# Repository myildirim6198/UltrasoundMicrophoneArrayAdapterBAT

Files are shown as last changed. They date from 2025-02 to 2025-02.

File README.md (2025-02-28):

# Ultrasound Microphone Array Adapter for recording and locating microbats

This project was developed as a final thesis project. This device records real-time Ultrasound of microbats that is inaudible to the human ears and makes those audible through usage of signal processing algorithms. Additionaly through using digital signal processing algorithms the device is capable of estimating the direction of arrival of the recorded microbat calls based on a microphone array with two MEMS-Microphones. This device is intended to be connected to end devices such as PCs, laptops and smartphones over USB-C. The signal processing is done on the end device.

# Hardware features

- MCU: STM32F730R8T6 with an ARM cortex M7 up to 216 MHz core clock
- Digital Connections: 1x USB-C Fullspeed up to 12 MBit/s, 1x USB-C up to 480 MBit/s (not tested) (connect one port at a time only!)
- Debug: Serial-Wire-Debug
- ADC: PCM1820 2 Channel Audio-ADC up to 192 kHz sampling Frequency
- Pre-amplifier stage: 21 dB
- Adjustable second amplifier stage: up to 40 dB
- Microphones: 2x KNOWLES SPU0410LR5H-QB MEMS-Microphones 3.4 mm gap to each other

# Applications:

- Microphone Arrays
- Ultrasound
- Bat detection and localisation

# Absolute Maximum Ratings

- Supply Voltage: +5V0 to +5V5 (recommended: +5V0) USB feeded

# Manufacturing Information

- Length = 50mm, Width = 50mm, Thickness = 1.6 mm
- Layers = 8
- Min. Via Hole diameter = 0.3 mm
- Via-Type: Epoxy Filled and Capped
- Impedance Control: JLC08161H-2116
- Surface Finish: ENIG
- Material Type: FR-4 TG155

# Progress

- Schematic design: complete
- Layouting: complete
- Manufacturing & assembly: complete
- Bring-Up: complete, all components tested except for USB-HS interface
- Firmware: complete, DMA-Based recording of ultrasound audio
- Software: complete, end-devices can process the recorded ultrasound audio samples frame based

# Examples

3D-representation of the Adapter

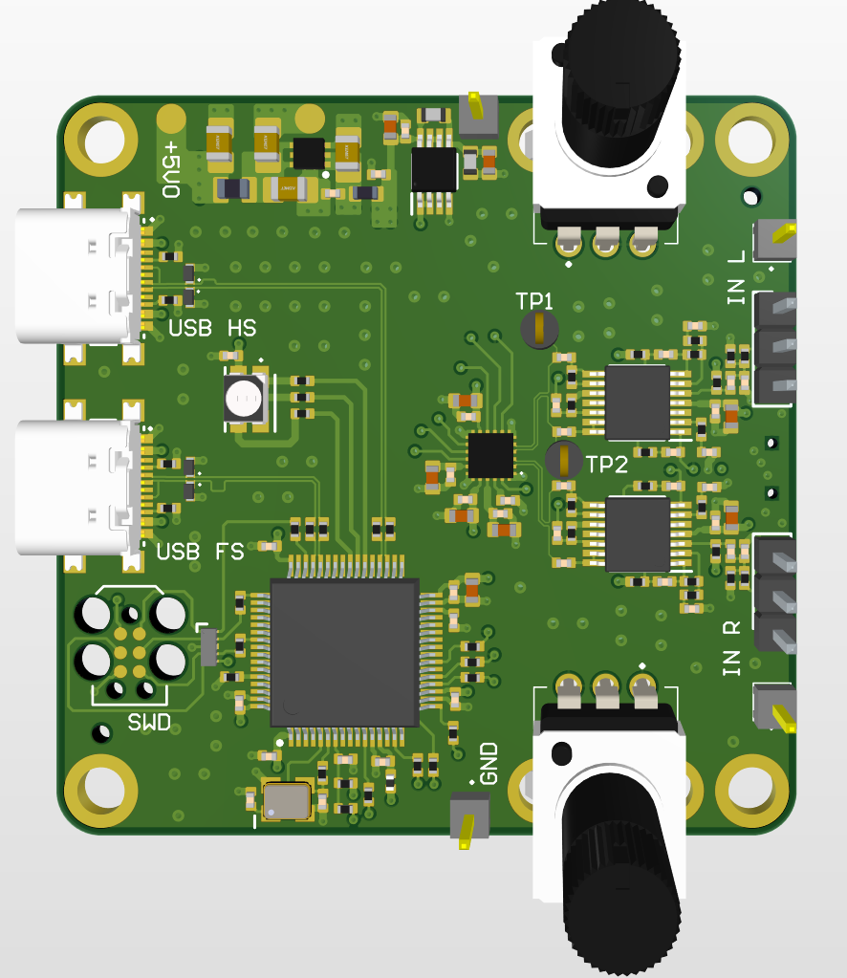
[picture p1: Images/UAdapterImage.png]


An ultrasound emitter that transmits frequencies between 30 kHz to 40 kHz was used to test the devices capabilities. Used sampling frequency is 160 kHz. For the localization the MUSIC-Algorithm was used. Used digital signal processing algorithms to make the microbat calls audible are heterodyne receiver (direct frequency mixing) and frequency dividers by using FIR polyphase decimation filters

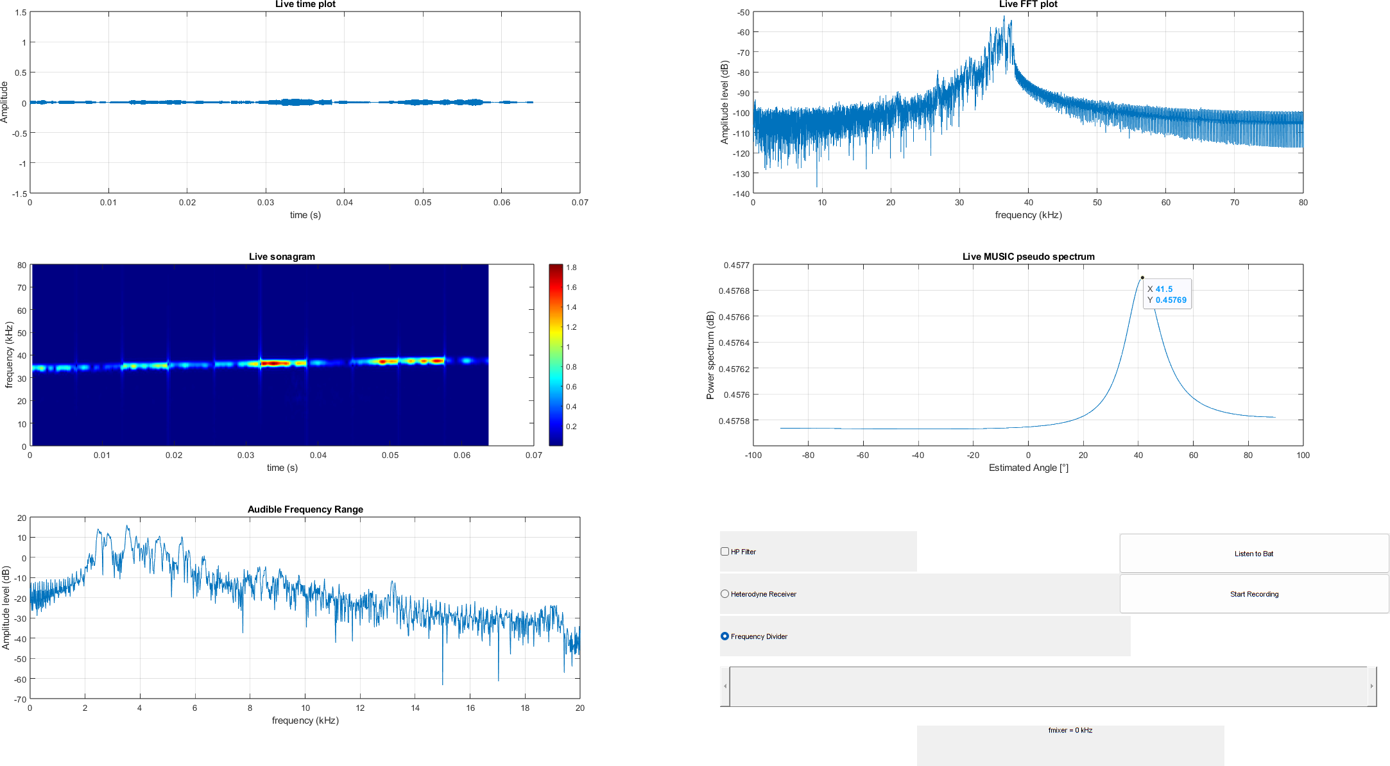
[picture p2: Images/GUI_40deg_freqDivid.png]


Example picture of the ultrasound adapter being recognized by a smartphone

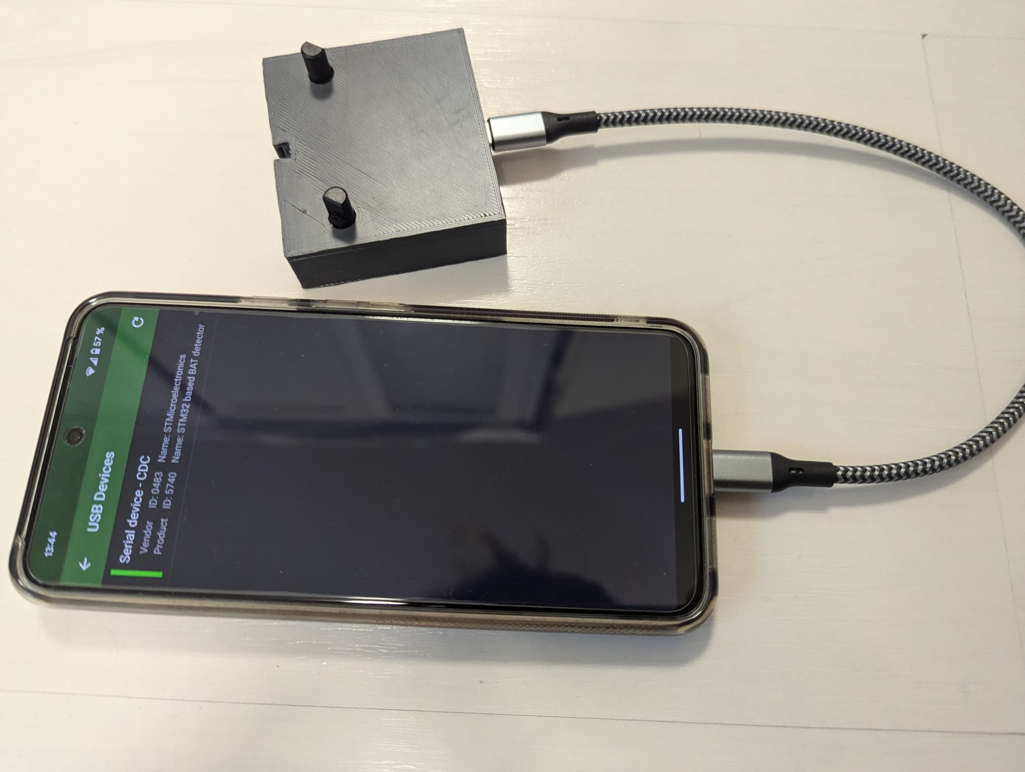
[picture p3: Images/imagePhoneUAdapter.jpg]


- Range: Up to 30 meters (tested with an ultrasound transmitter Kemo M094N with 120 dB SPL)

- Firmware code: included

- Software code:
A barebone loopback project in MATLAB/GNU Octave is included.
The developed software code / app implementing the signal processing algorithms is also included. Due to lack of time the software code could not be optimized to remove the growing latency of updating plots on weaker hardware. Tested on Windows 11 on a Custom built PC (Ryzen 7 5800X3D + 32 GByte DDR4 RAM) with no noticable latencys. Tested on Windows 11 on a Laptop (Surface Pro 8 with i7 configuration and 16 GByte of LPDDR4 RAM) with increasing latency.

To improve the accuracy of localisation it is recommended to relocate the connector adapters on the PCB to the bottom side or bridge the through hole pads between middle and near the microphones with solder for each channel seperately. The outer trough hole pads are for inputs for the usage of a function generator.

I make no guarantees as to device funtionality. Please review the components, schematics carefully before production.

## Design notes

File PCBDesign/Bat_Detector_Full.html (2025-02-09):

Reporting Options

# File in Newer Format

Date | : | 14.12.2024
Time | : | 20:38:12
Filename | : | D:\Users\Muhammed\Documents\Masterthesis\AltiumPCBs\Bat_Detector_Full\Bat_Detector_Full.PrjPcb

Version | Warning

Release 23.10

CAUTION - This project contains rules defined using the Constraint Manager. You are seeing this message for two possible reasons. Firstly, this is an older version of the software that does not support this feature, in which case design rules will fall back to being presented as standard, query-based rules. If you save the PCB project in this older version of Altium Designer, all Constraint Manager data structure information will be lost. Secondly, if this software version does support the feature, then you currently don't have the level of Altium Designer Software Subscription (Pro/Enterprise) to be able to edit constraints using the Constraint Manager, in which case it will present rules in view only mode.

This file was generated by a later version of the software

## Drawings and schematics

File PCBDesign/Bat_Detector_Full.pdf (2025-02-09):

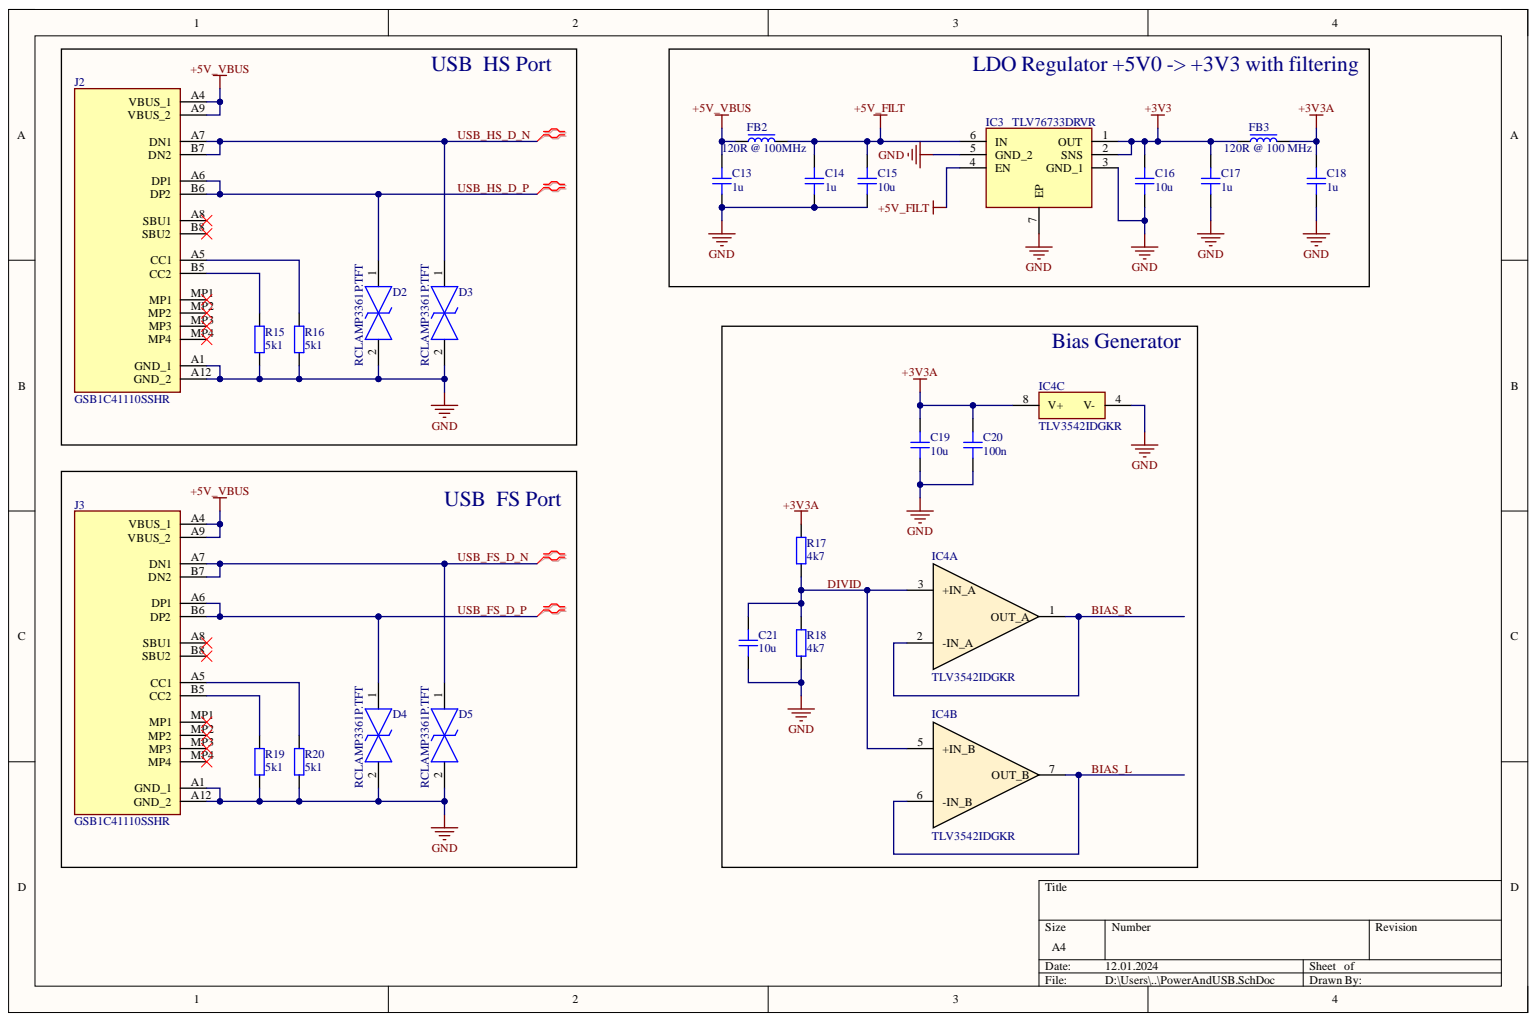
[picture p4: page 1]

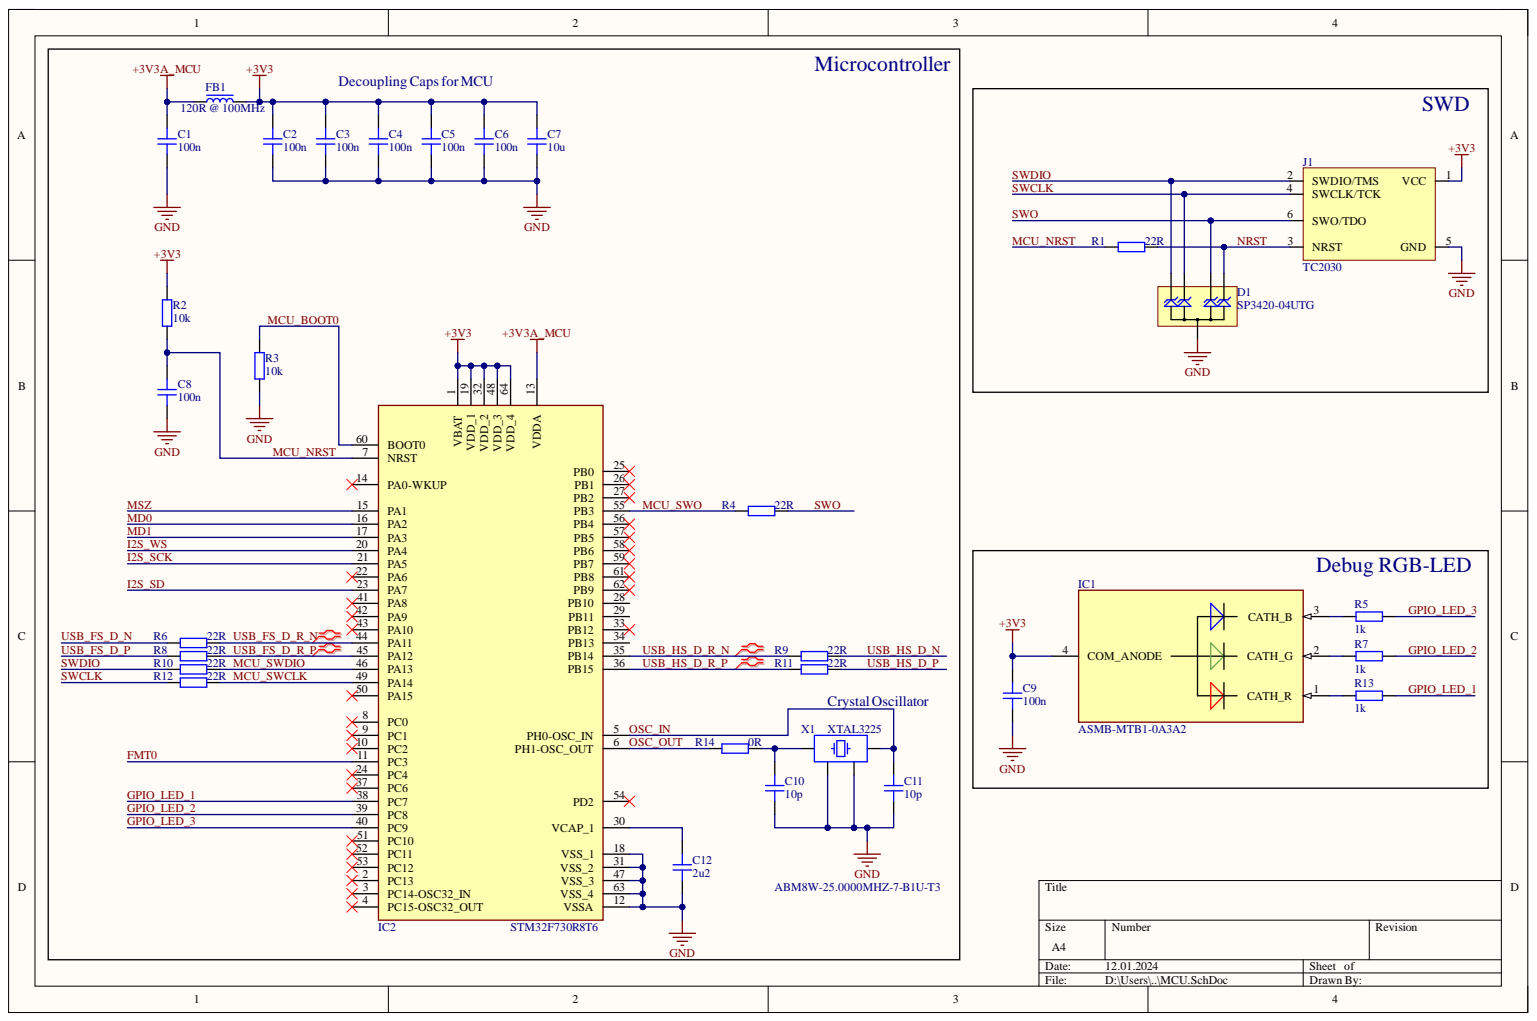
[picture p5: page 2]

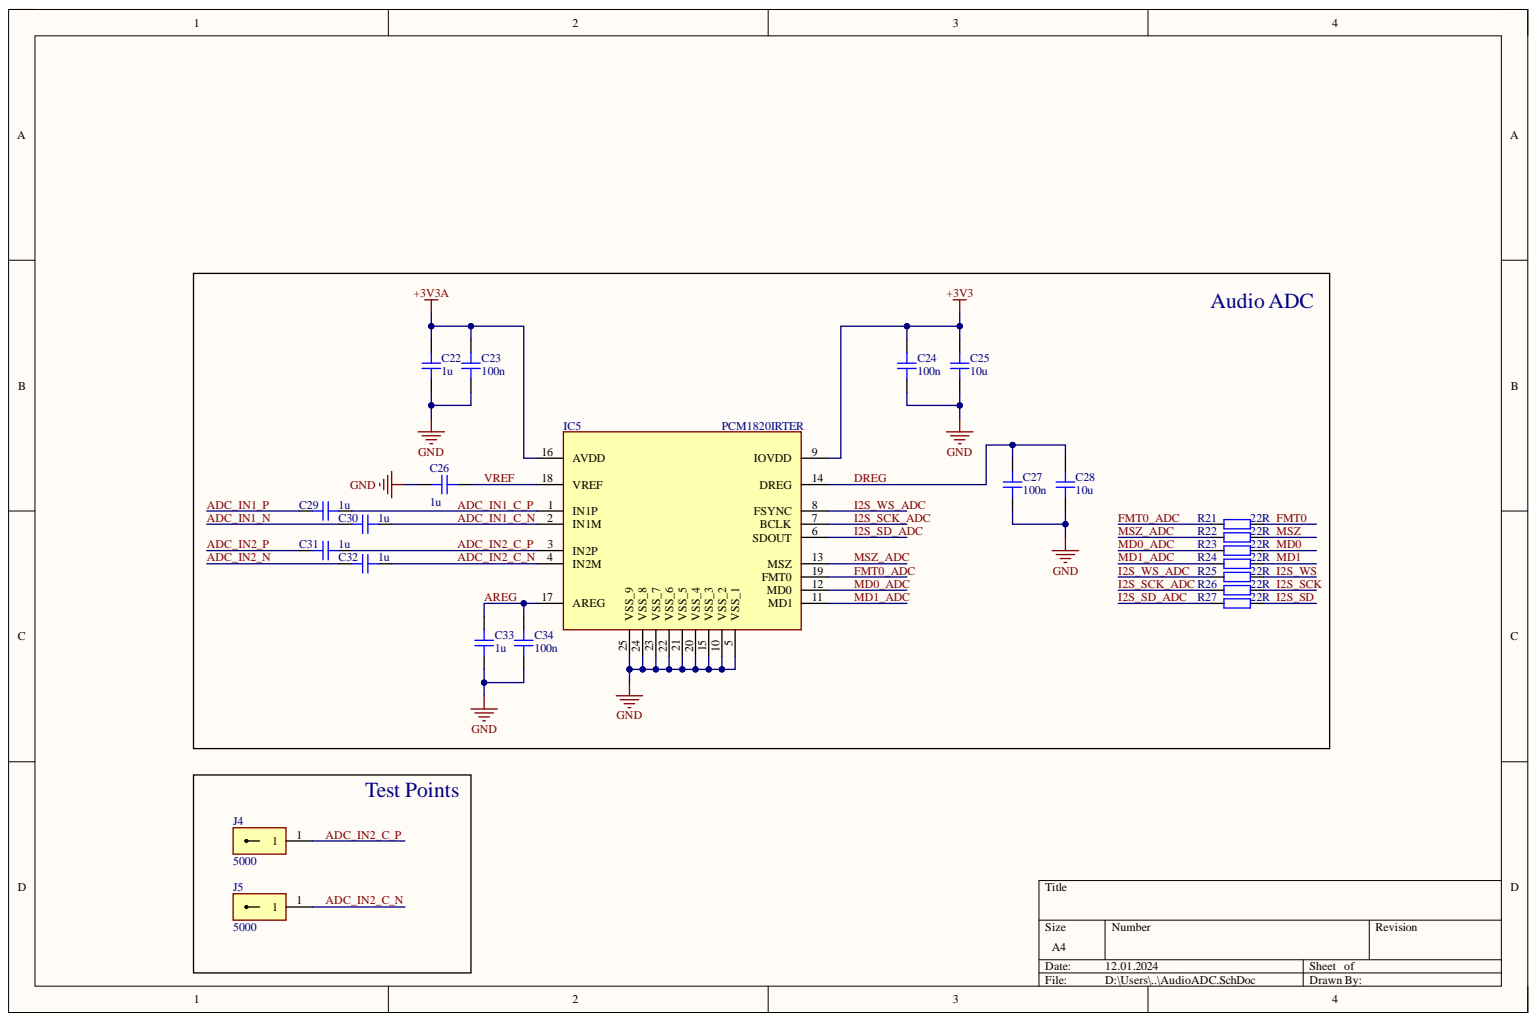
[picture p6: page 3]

ADC_IN1_C_N | IN1M 2 | I2S_SCK_ADC

IN2P 3 | I2S_SD_ADC

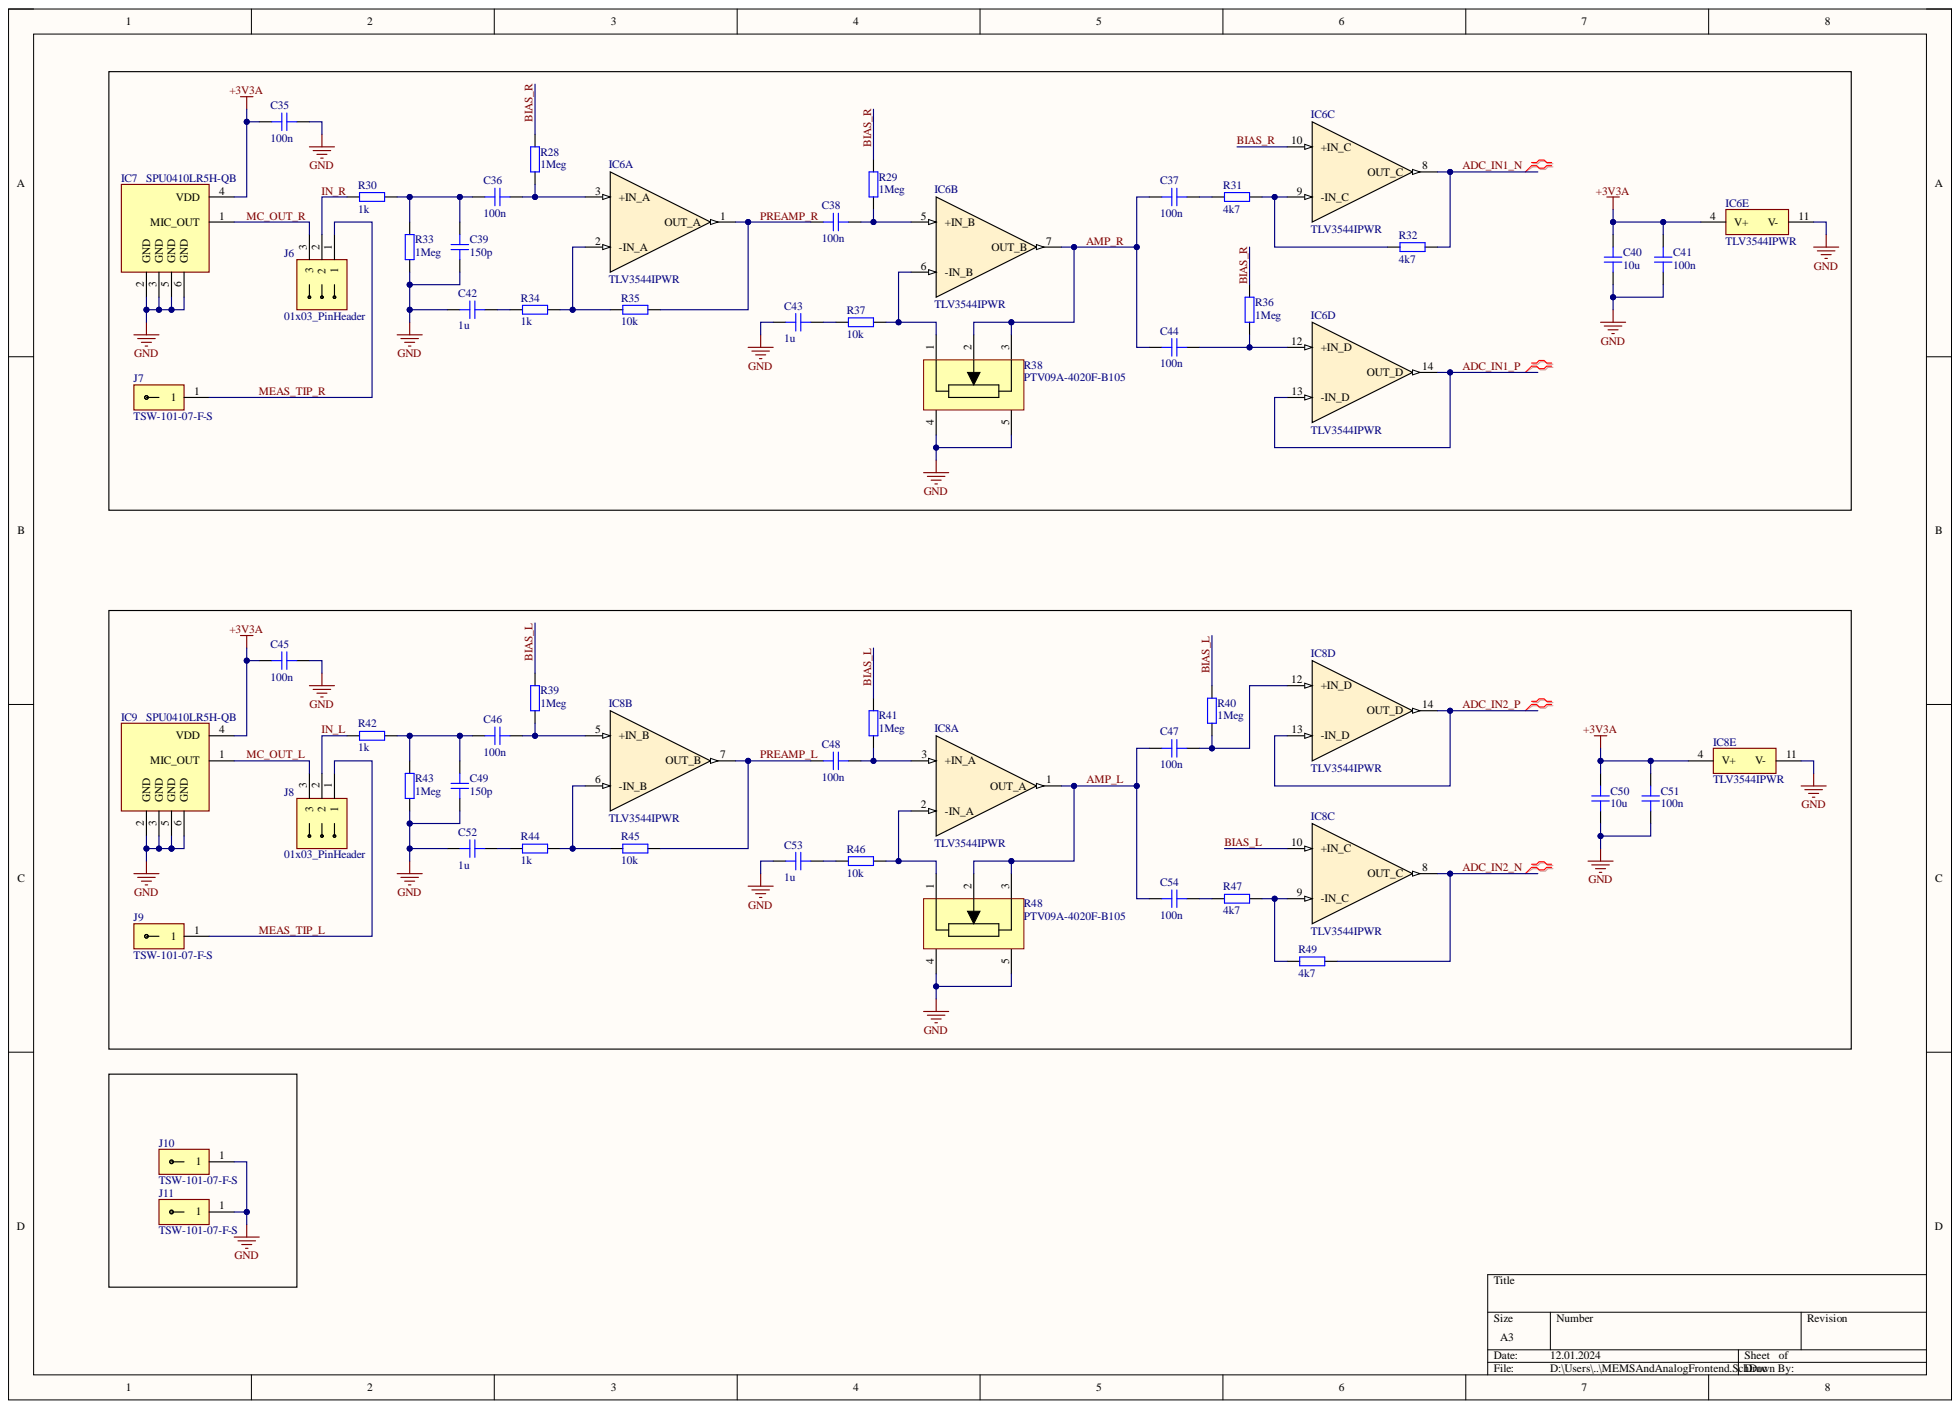
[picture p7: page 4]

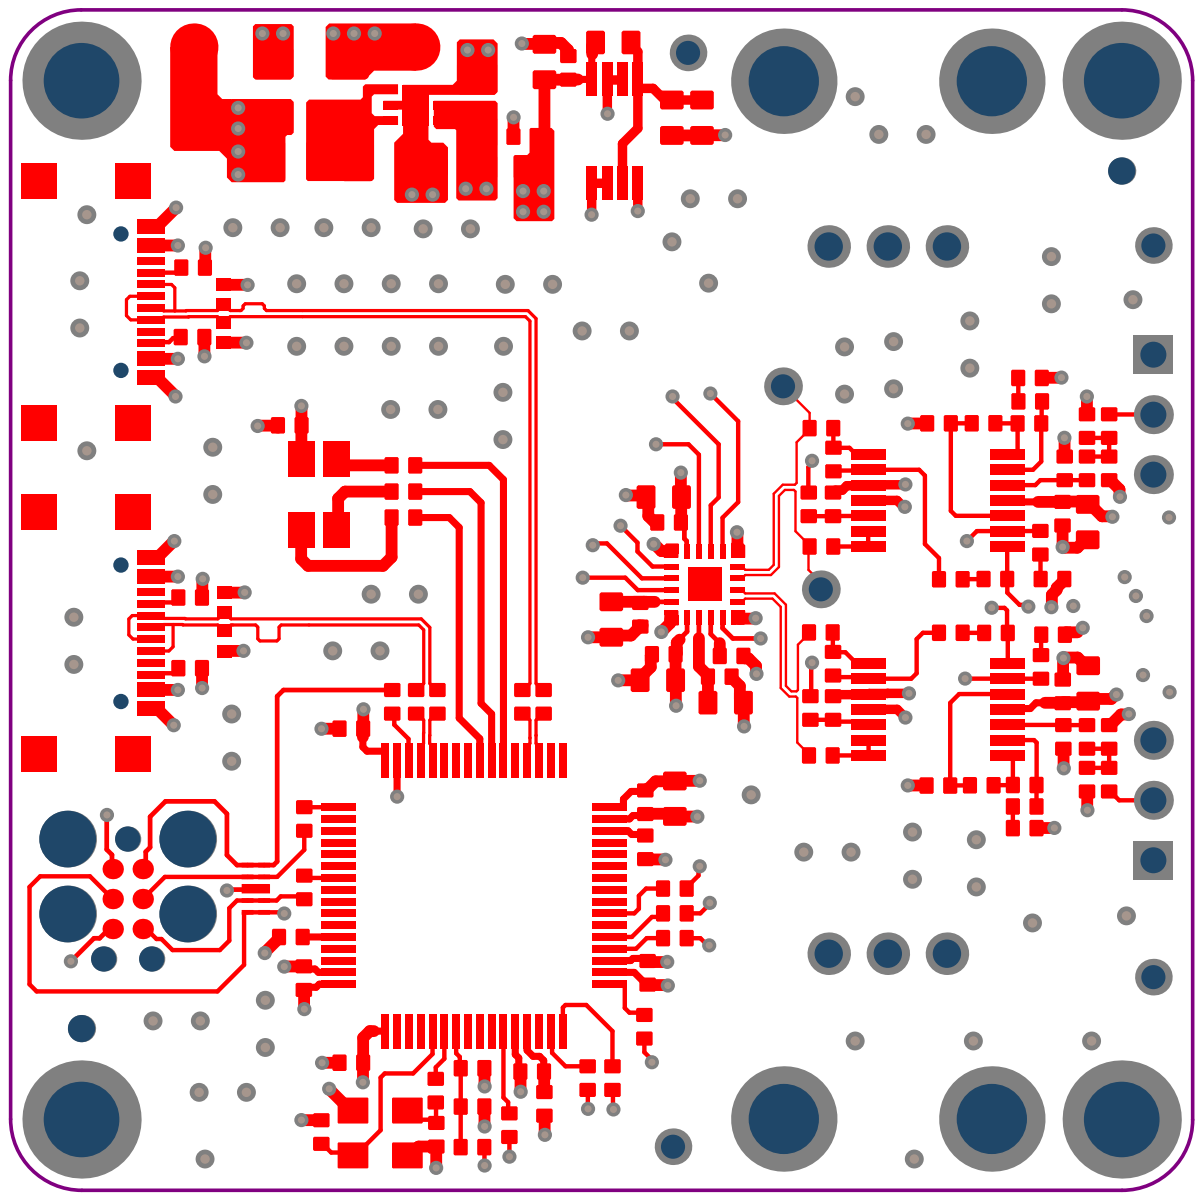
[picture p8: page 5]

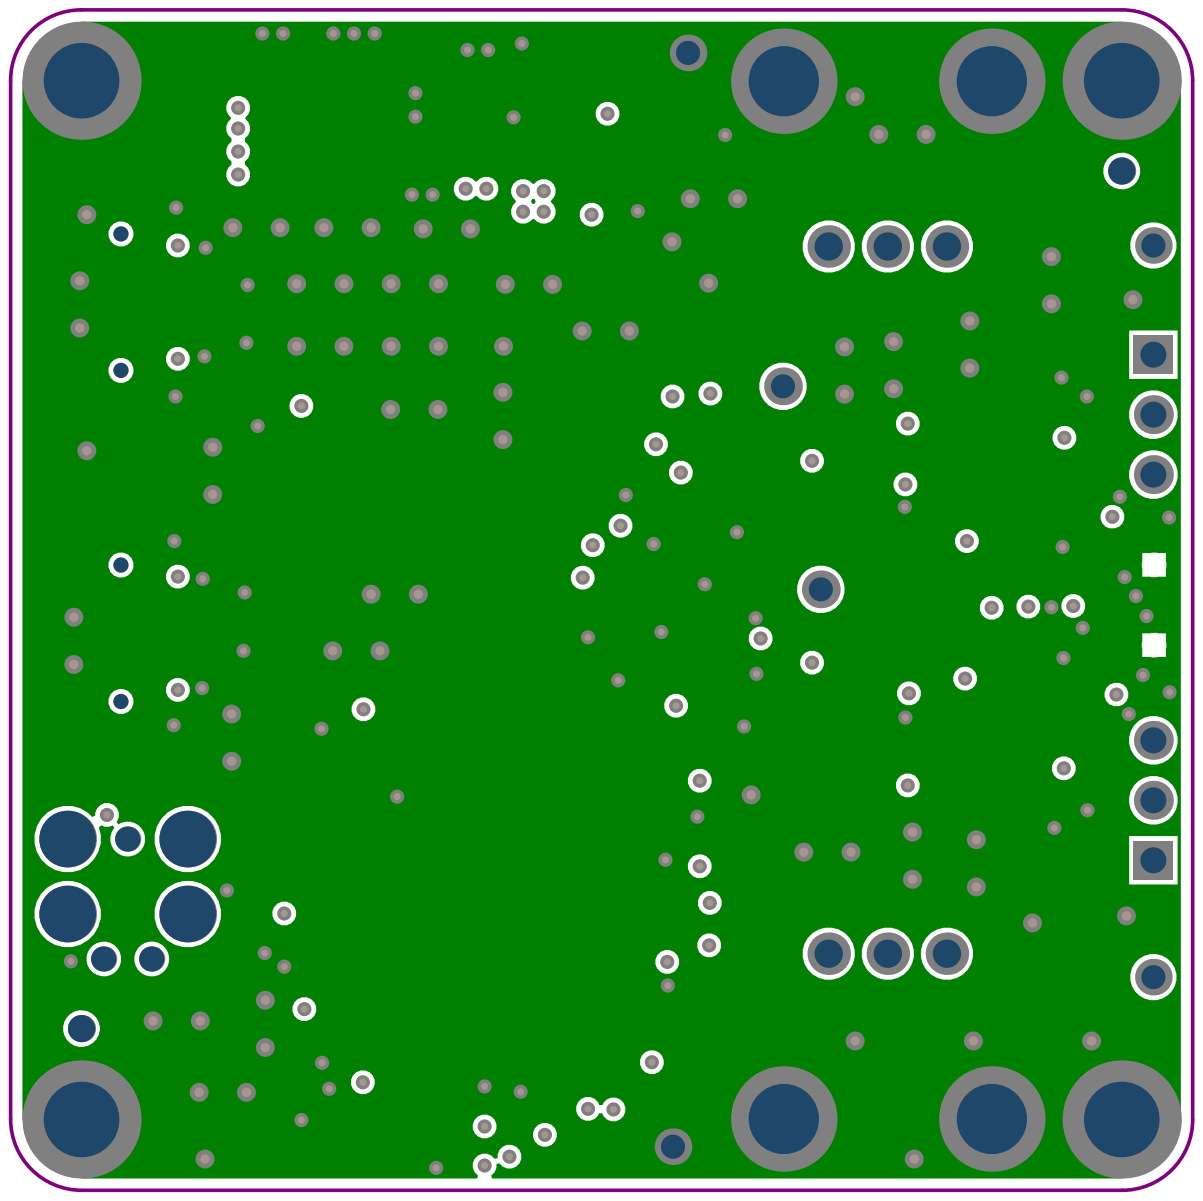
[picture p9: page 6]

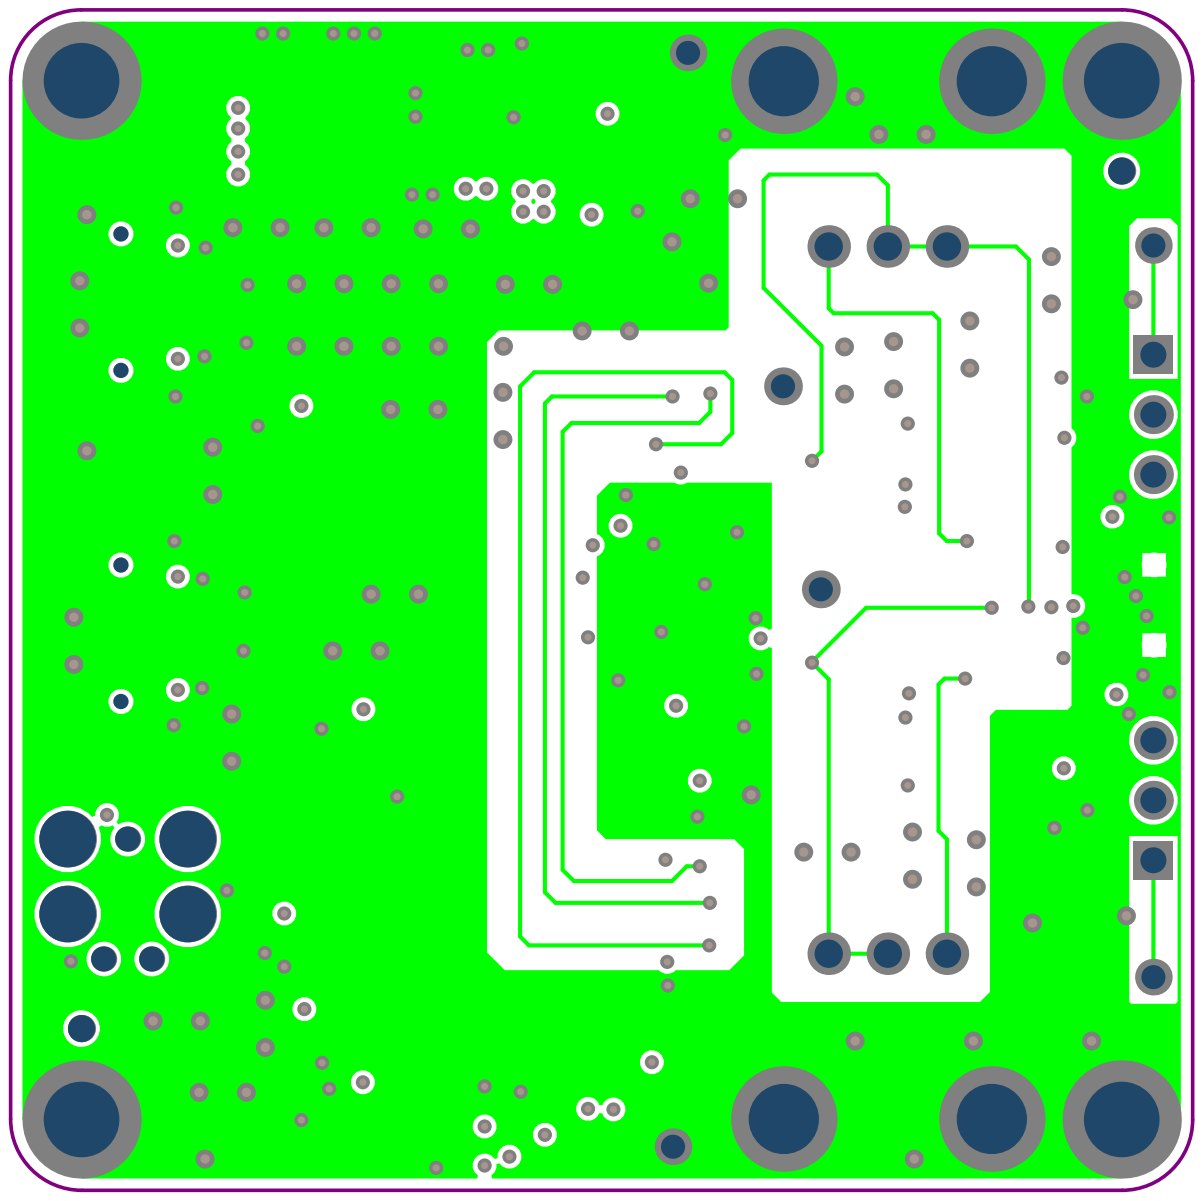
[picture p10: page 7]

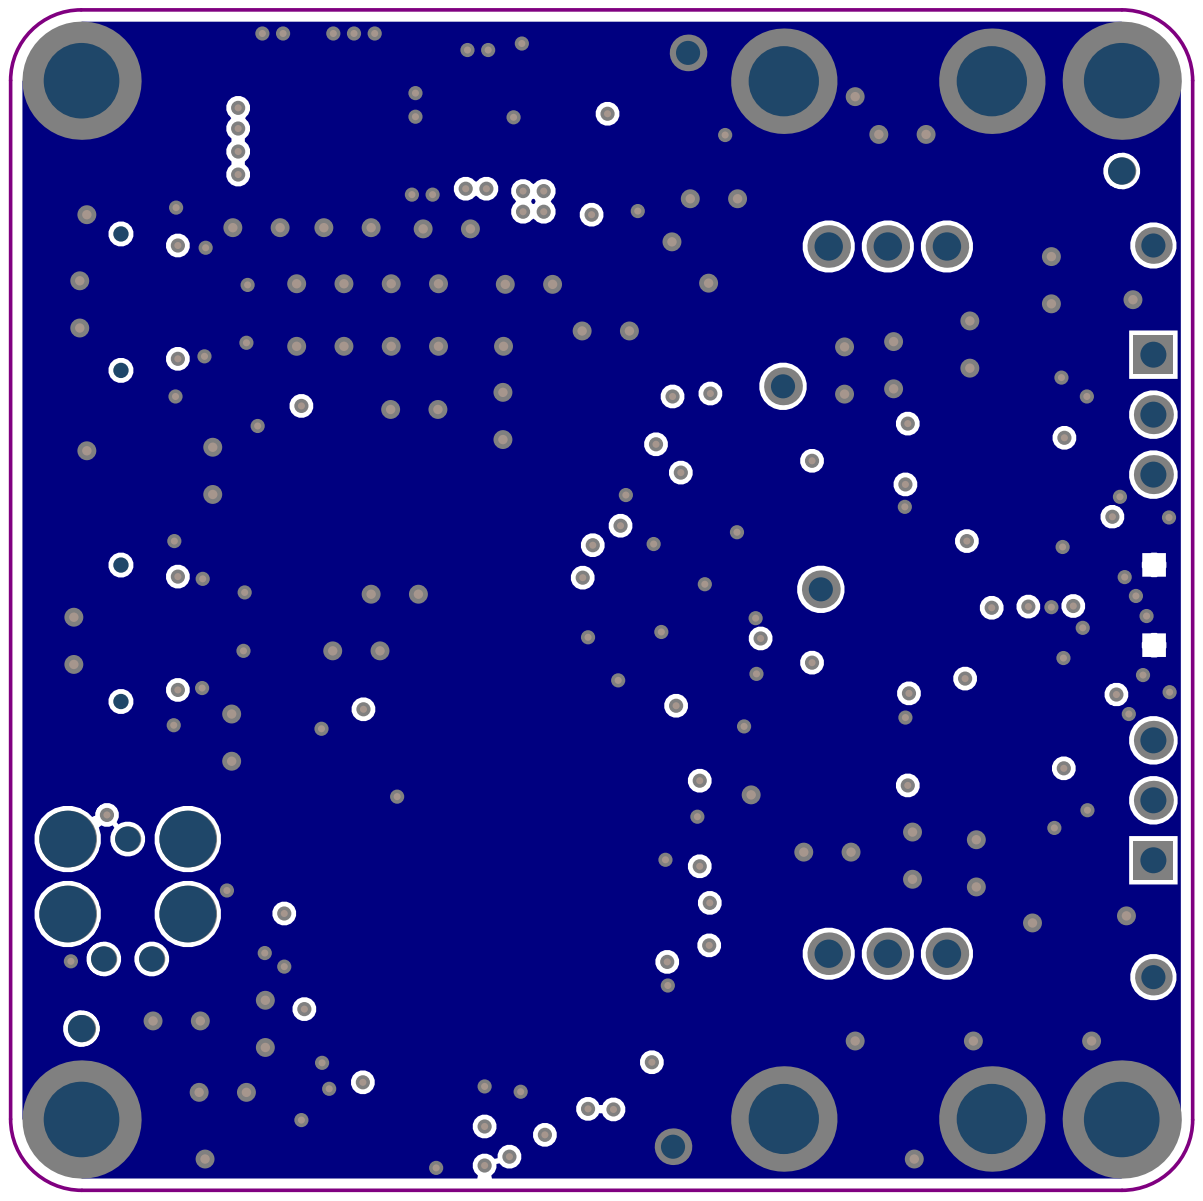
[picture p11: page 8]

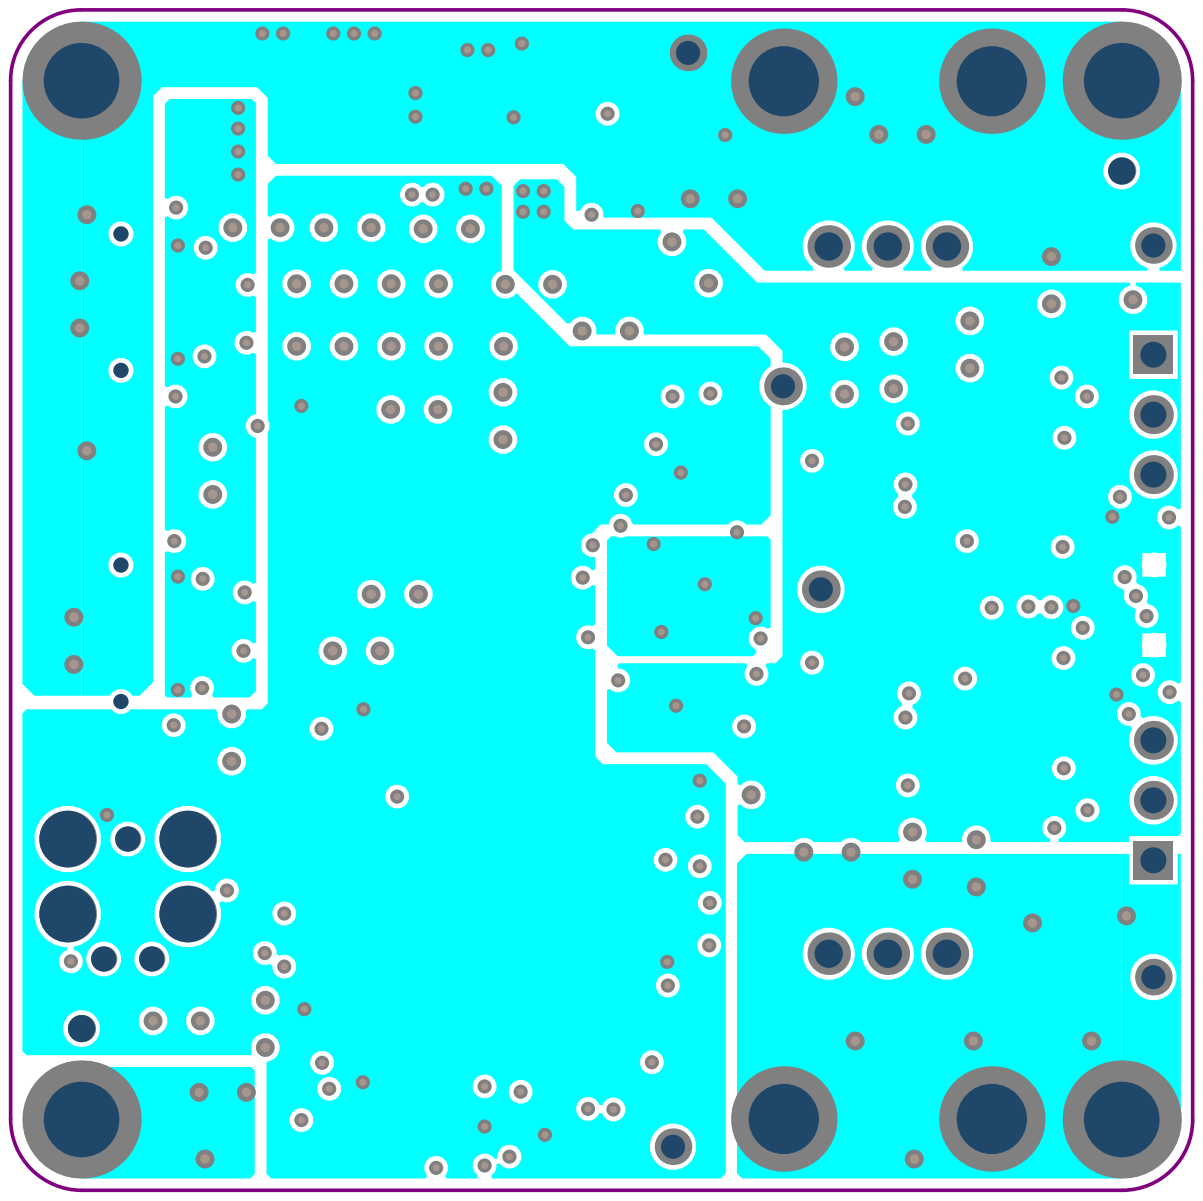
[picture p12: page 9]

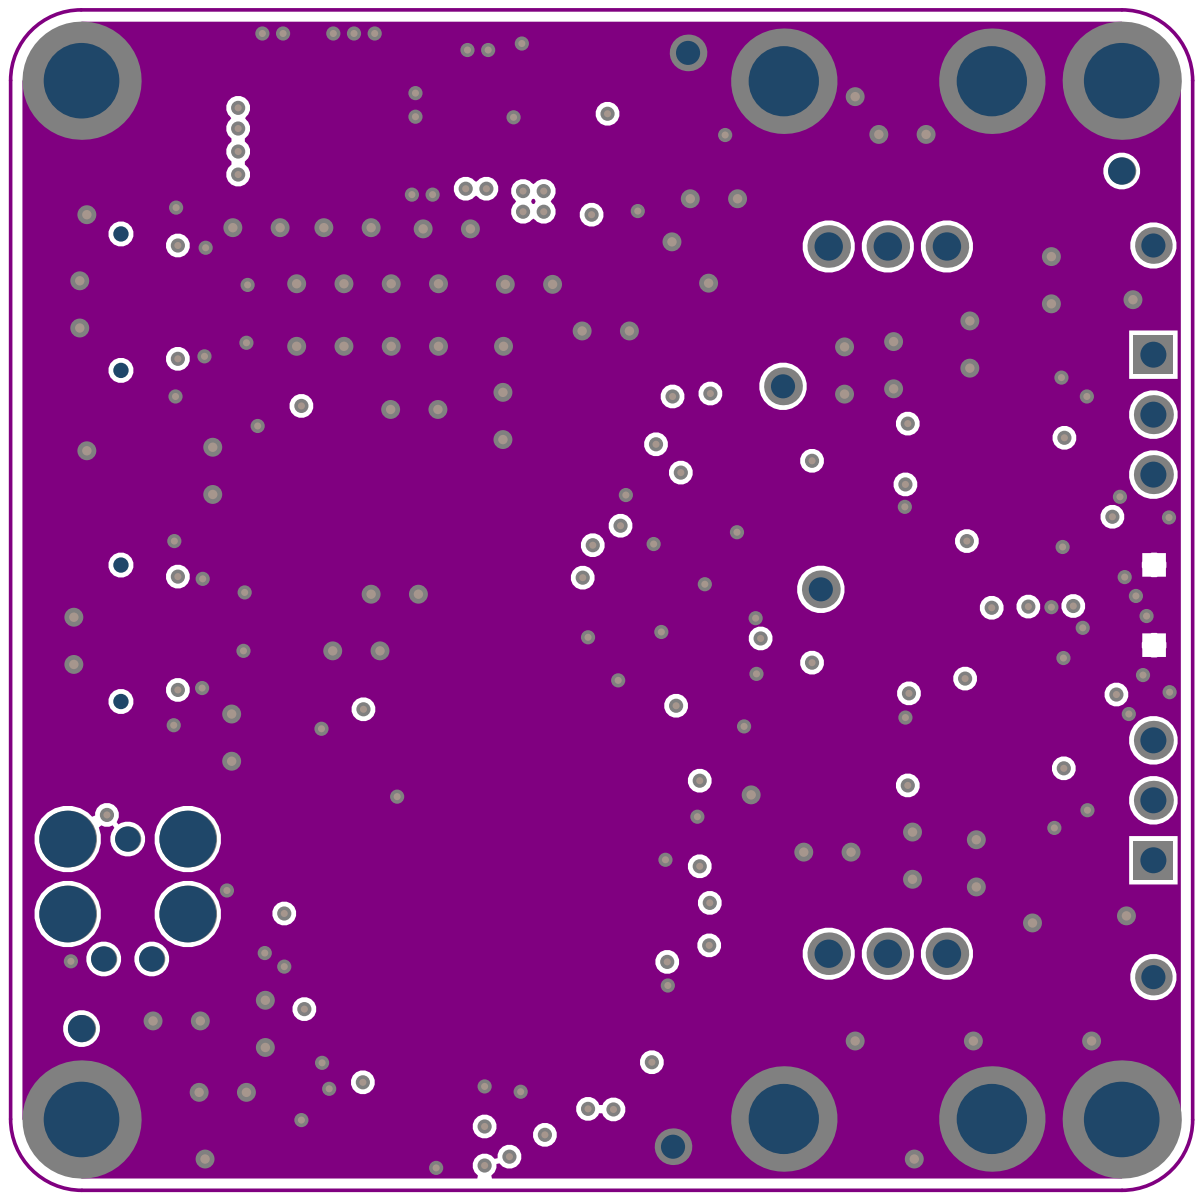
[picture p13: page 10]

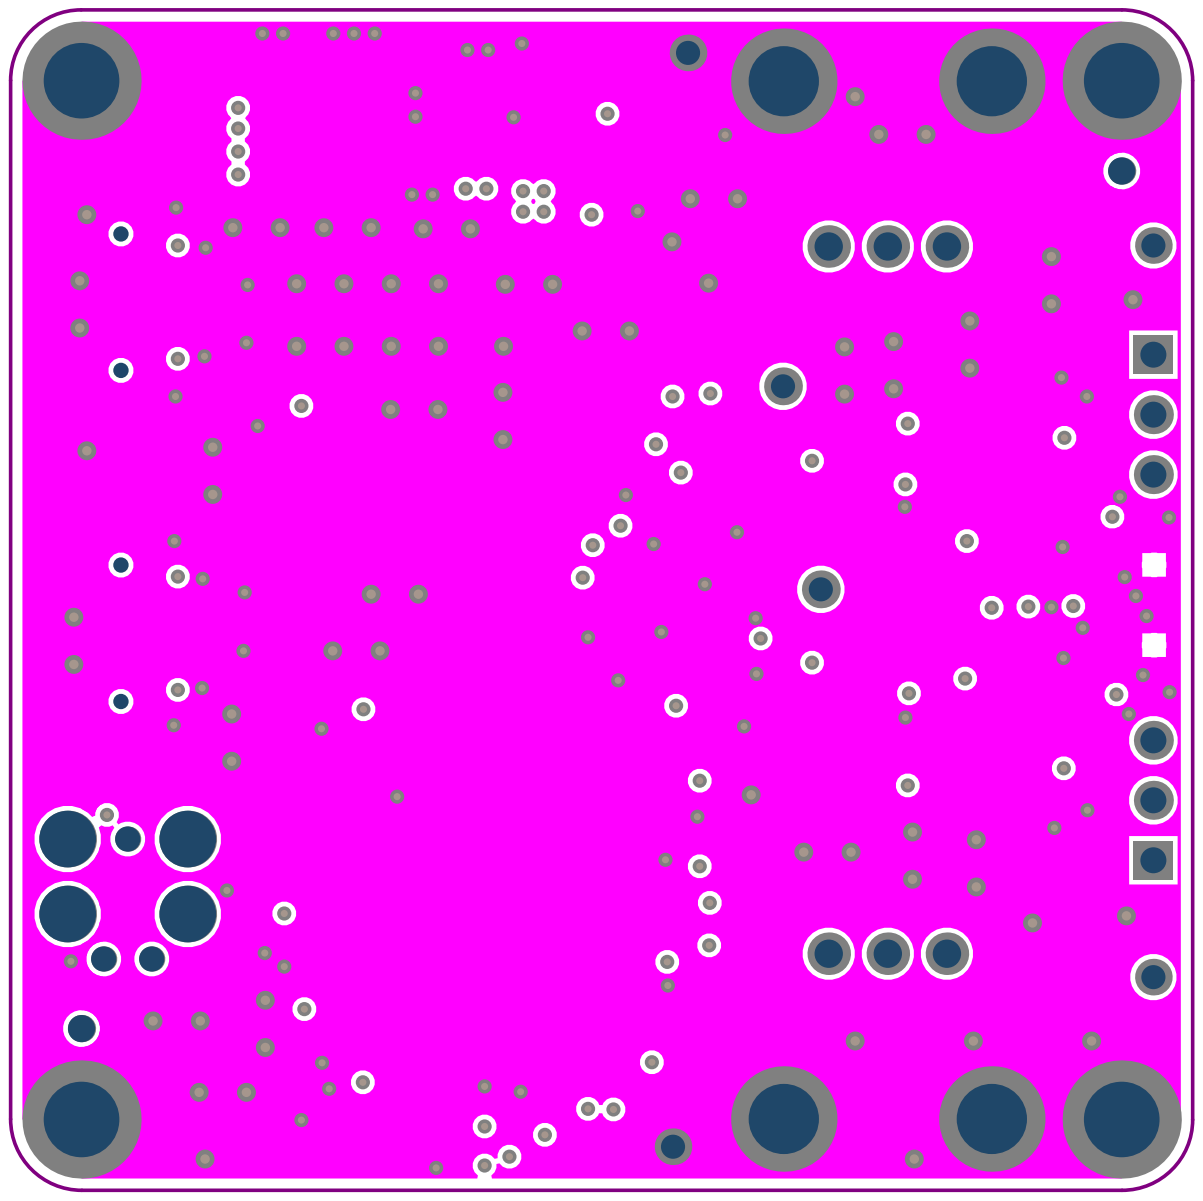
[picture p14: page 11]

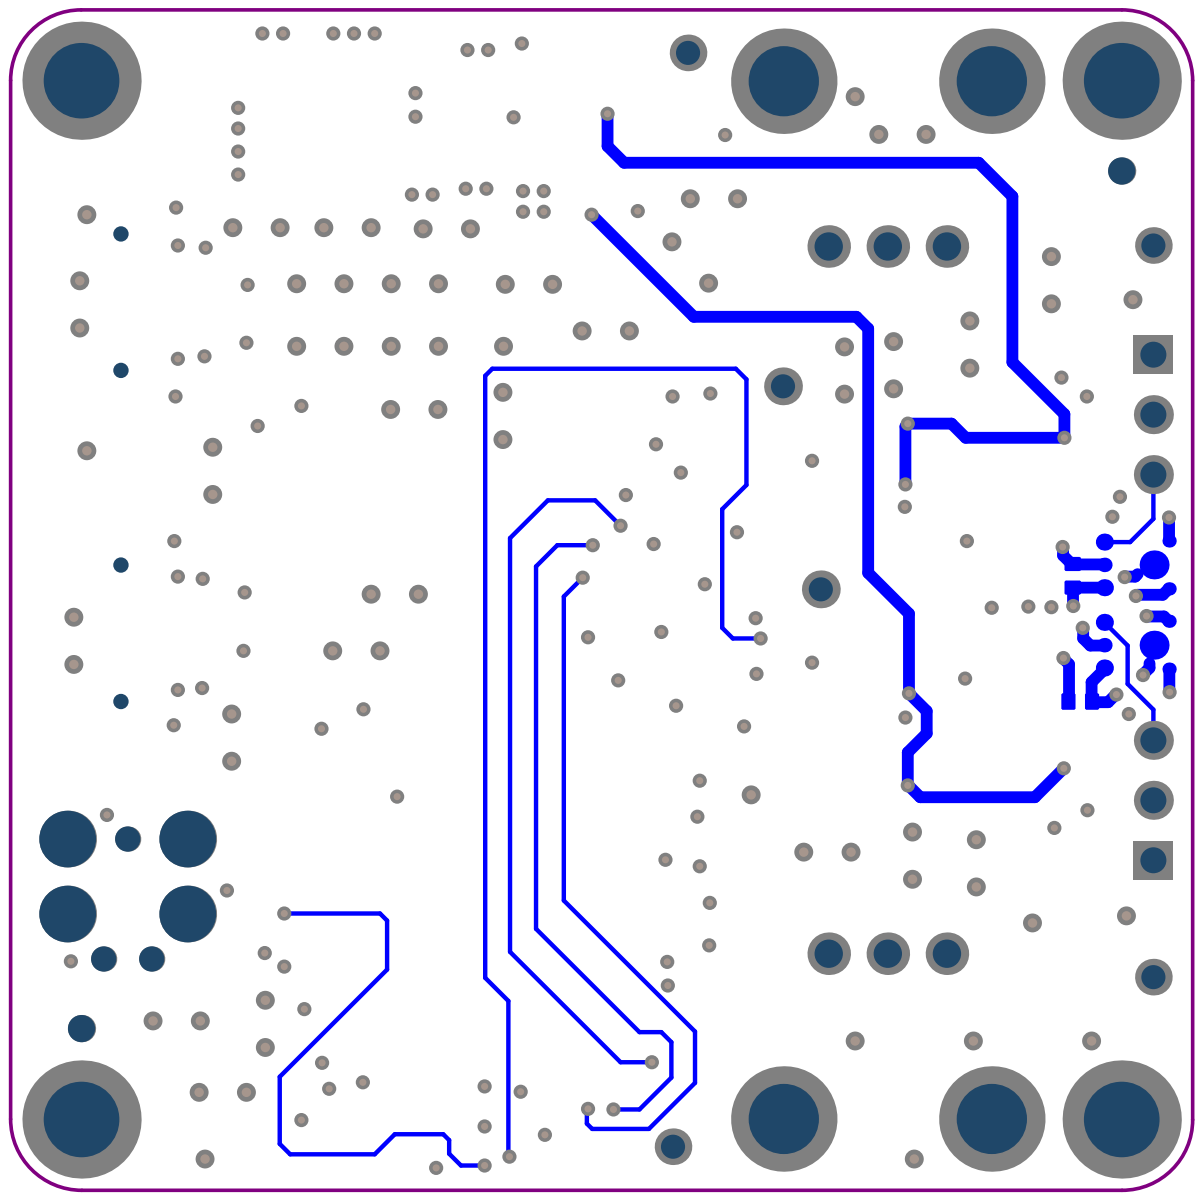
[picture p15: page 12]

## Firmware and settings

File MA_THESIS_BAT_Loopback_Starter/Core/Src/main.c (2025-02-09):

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
/* Includes ------------------------------------------------------------------*/
#include "main.h"
#include "usb_device.h"

/* USER CODE BEGIN Includes */
#include "usbd_cdc_if.h"
/* USER CODE END Includes */


I2S_HandleTypeDef hi2s1;
DMA_HandleTypeDef hdma_spi1_rx;

void SystemClock_Config(void);
static void MPU_Config(void);
static void MX_GPIO_Init(void);
static void MX_DMA_Init(void);
static void MX_I2S1_Init(void);
/* USER CODE BEGIN PFP */
void HAL_I2S_RxHalfCpltCallback(I2S_HandleTypeDef *hi2s);
void HAL_I2S_RxCpltCallback(I2S_HandleTypeDef *hi2s);
/* USER CODE END PFP */

/* USER CODE BEGIN 0 */
#define ADC_BUFF_SZ 4096*2
#define USB_BUFF_SZ 2048

uint16_t adcBuff[ADC_BUFF_SZ];
volatile int32_t usbBuff[USB_BUFF_SZ];

volatile int32_t usbBuff1[USB_BUFF_SZ];
volatile int32_t usbBuff2[USB_BUFF_SZ];

volatile short dataReady;
/* USER CODE END 0 */

/**
  * @brief  The application entry point.
  * @retval int
  */
int main(void)
{

  /* MPU Configuration--------------------------------------------------------*/
  MPU_Config();

  /* MCU Configuration--------------------------------------------------------*/

  /* Reset of all peripherals, Initializes the Flash interface and the Systick. */
  HAL_Init();

  /* USER CODE BEGIN Init */
  HAL_Delay(1000); // wait for adc powerup before applying I2S clocks
  /* USER CODE END Init */

  /* Configure the system clock */
  SystemClock_Config();

  /* Initialize all configured peripherals */
  MX_GPIO_Init();
  MX_DMA_Init();
  MX_I2S1_Init();
  MX_USB_DEVICE_Init();
  /* USER CODE BEGIN 2 */
  HAL_I2S_Receive_DMA(&hi2s1, adcBuff, ADC_BUFF_SZ/2);

  /* USER CODE END 2 */

  /* Infinite loop */
  /* USER CODE BEGIN WHILE */
  while (1)
  {
    /* USER CODE END WHILE */

    /* USER CODE BEGIN 3 */

  }
  /* USER CODE END 3 */
}

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
/* USER CODE BEGIN 4 */
/**
  * @brief I2S DMA Half complete callback interrupt handler
  * @param I2S_HandleTypeDef *hi2s the I2S handler
  * @retval None
  */
void HAL_I2S_RxHalfCpltCallback(I2S_HandleTypeDef *hi2s){
	int usbBuffcntr = 0;
	// reconstruct left-right samples and fill first half of ADC-buffer to separate USB-buffer
	for(int i = 0; i < ADC_BUFF_SZ/2; i = i + 4){
		usbBuff1[usbBuffcntr] = (int) (adcBuff[i] << 16) | adcBuff[i + 1];
		usbBuff1[usbBuffcntr + 1] = (int) (adcBuff[i + 2] << 16) | adcBuff[i + 3];
		usbBuffcntr++;
		usbBuffcntr++;
	}
	CDC_Transmit_FS((uint8_t*) usbBuff1, USB_BUFF_SZ * 4);
}

/**
  * @brief I2S DMA complete callback interrupt handler
  * @param I2S_HandleTypeDef *hi2s the I2S handler
  * @retval None
  */
void HAL_I2S_RxCpltCallback(I2S_HandleTypeDef *hi2s) {
	//int usbBuffcntr = USB_BUFF_SZ/2;
	int usbBuffcntr = 0;
	// reconstruct left-right samples and fill final half of ADC-buffer to separate USB-buffer
	for(int i = ADC_BUFF_SZ/2; i < ADC_BUFF_SZ; i = i + 4){
		usbBuff2[usbBuffcntr] = (int) (adcBuff[i] << 16) | adcBuff[i + 1];
		usbBuff2[usbBuffcntr + 1] = (int) (adcBuff[i + 2] << 16) | adcBuff[i + 3];
		usbBuffcntr++;
		usbBuffcntr++;
	}
	CDC_Transmit_FS((uint8_t*) usbBuff2, USB_BUFF_SZ * 4);
}
/* USER CODE END 4 */

 /* MPU Configuration */

void MPU_Config(void)
{
  MPU_Region_InitTypeDef MPU_InitStruct = {0};

  /* Disables the MPU */
  HAL_MPU_Disable();

  /** Initializes and configures the Region and the memory to be protected
  */
  MPU_InitStruct.Enable = MPU_REGION_ENABLE;
  MPU_InitStruct.Number = MPU_REGION_NUMBER0;
  MPU_InitStruct.BaseAddress = 0x0;
  MPU_InitStruct.Size = MPU_REGION_SIZE_4GB;
  MPU_InitStruct.SubRegionDisable = 0x87;
  MPU_InitStruct.TypeExtField = MPU_TEX_LEVEL0;
  MPU_InitStruct.AccessPermission = MPU_REGION_NO_ACCESS;
  MPU_InitStruct.DisableExec = MPU_INSTRUCTION_ACCESS_DISABLE;
  MPU_InitStruct.IsShareable = MPU_ACCESS_SHAREABLE;
  MPU_InitStruct.IsCacheable = MPU_ACCESS_NOT_CACHEABLE;
  MPU_InitStruct.IsBufferable = MPU_ACCESS_NOT_BUFFERABLE;

  HAL_MPU_ConfigRegion(&MPU_InitStruct);
  /* Enables the MPU */
  HAL_MPU_Enable(MPU_PRIVILEGED_DEFAULT);

}

/**
  * @brief  This function is executed in case of error occurrence.
  * @retval None
  */
void Error_Handler(void)
{
  /* USER CODE BEGIN Error_Handler_Debug */
  /* User can add his own implementation to report the HAL error return state */
  __disable_irq();
  while (1)
  {
  }
  /* USER CODE END Error_Handler_Debug */
}

#ifdef  USE_FULL_ASSERT
/**
  * @brief  Reports the name of the source file and the source line number
  *         where the assert_param error has occurred.
  * @param  file: pointer to the source file name
  * @param  line: assert_param error line source number
  * @retval None
  */
void assert_failed(uint8_t *file, uint32_t line)
{
  /* USER CODE BEGIN 6 */
  /* User can add his own implementation to report the file name and line number,
     ex: printf("Wrong parameters value: file %s on line %d\r\n", file, line) */
  /* USER CODE END 6 */
}
#endif /* USE_FULL_ASSERT */

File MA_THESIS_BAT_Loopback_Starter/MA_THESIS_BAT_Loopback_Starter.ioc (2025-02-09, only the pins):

Mcu.UserName=STM32F730R8Tx
PA1.Signal=GPIO_Output
PA11.Signal=USB_OTG_FS_DM
PA12.Signal=USB_OTG_FS_DP
PA13.Signal=SYS_JTMS-SWDIO
PA14.Signal=SYS_JTCK-SWCLK
PA2.Signal=GPIO_Output
PA3.Signal=GPIO_Output
PA4.Signal=I2S1_WS
PA5.Signal=I2S1_CK
PA7.Signal=I2S1_SD
PB3.Signal=SYS_JTDO-SWO
PC3.Signal=GPIO_Output
PC7.Signal=GPIO_Output
PC8.Signal=GPIO_Output
PC9.Signal=GPIO_Output
PH0-OSC_IN.Signal=RCC_OSC_IN
PH1-OSC_OUT.Signal=RCC_OSC_OUT

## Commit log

2025-02-09 Main Commit
    [AudioADC.SchDoc, Bat_Detector_Full.PrjPcb, MCU.SchDoc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]
2025-02-09 Added STM32 Firmware Project

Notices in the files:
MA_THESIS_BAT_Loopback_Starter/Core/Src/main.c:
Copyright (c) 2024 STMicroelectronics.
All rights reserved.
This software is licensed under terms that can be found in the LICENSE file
